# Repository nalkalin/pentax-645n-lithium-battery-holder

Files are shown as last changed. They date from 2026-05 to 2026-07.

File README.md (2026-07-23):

# Pentax 645N / 645N II Lithium Battery Holder

3D-printable battery holder for converting a Pentax 645N/645N II battery holder to rechargeable lithium power. The current design uses two 3.7 V lithium cells in series (2S: 7.4 V nominal, 8.4 V fully charged) with a 2S USB-C charge/boost module.

中文版: [点此跳转](README.zh-CN.md)

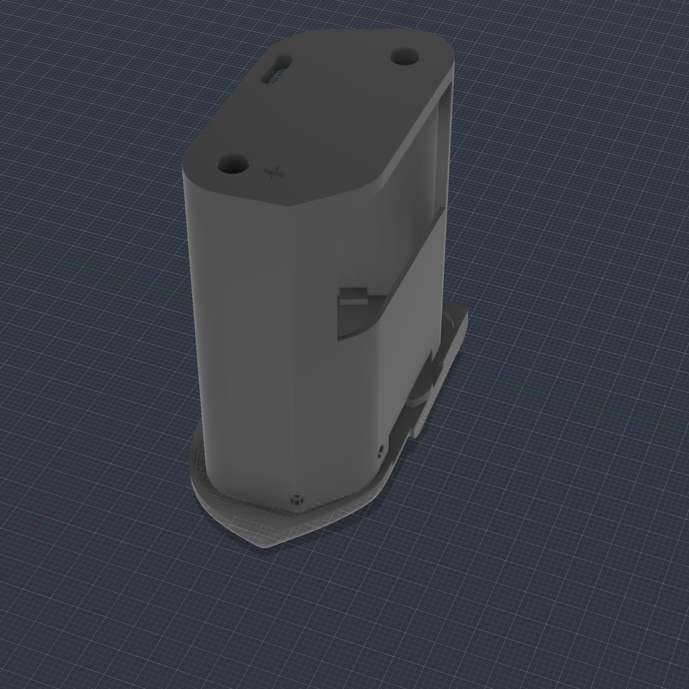
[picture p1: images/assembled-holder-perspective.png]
Assembled holder render


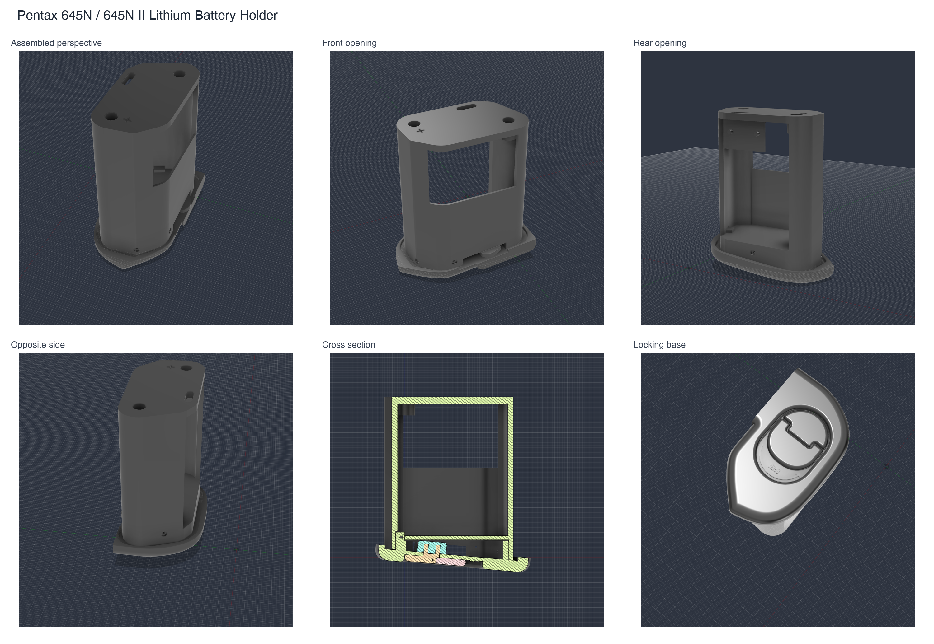
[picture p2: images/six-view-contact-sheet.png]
Six-view contact sheet


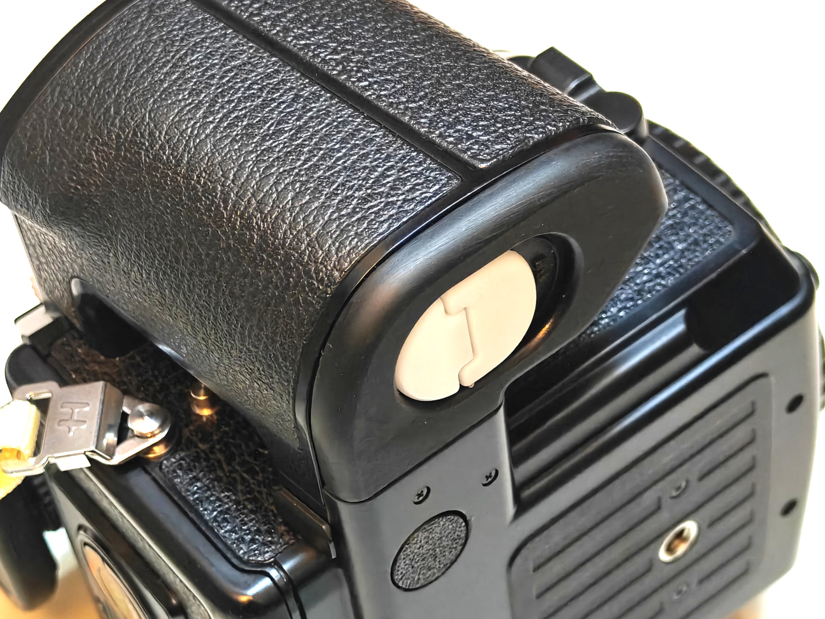
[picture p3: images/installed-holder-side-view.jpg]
Installed holder, side view


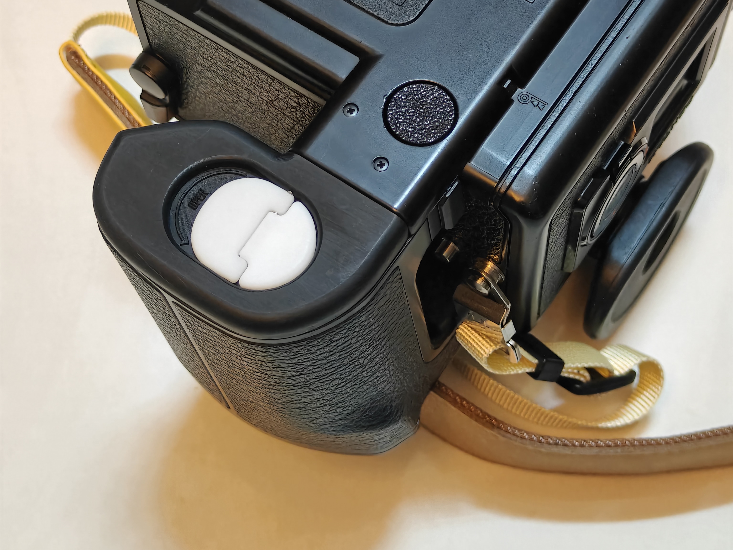
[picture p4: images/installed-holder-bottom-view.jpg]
Installed holder, bottom view


> Safety note: this is a DIY camera power modification. Use two cells of the same model, capacity, age, and state of charge. Verify the module output voltage, polarity, and absence of shorts with a multimeter before inserting the holder into a camera. Insulate all joints and contacts, and never use damaged, swollen, or overheating cells.

## Design Philosophy

The original Pentax 645N/645N II battery holder uses six AA alkaline batteries. That works, but it is not ideal for frequent use: disposable alkaline cells create avoidable waste, need to be replaced often, and make it easy to end up carrying extra batteries just to keep the camera running.

This project replaces that consumable setup with a rechargeable lithium pack. The goal is to keep these medium-format cameras practical for daily use while reducing reliance on single-use AA cells. Two series-connected lithium cells with a 2S charge/boost module offer several advantages:

- Rechargeable power instead of repeatedly buying and discarding alkaline batteries.
- USB-C charging, including from a wall charger, power bank, or field charging setup.
- A 7.4 V nominal 2S pack is sufficient regarding the voltage required by the camera.

## Compatible Models

- Pentax 645N
- Pentax 645N II

## Repository Contents

| Path | Description |
| --- | --- |
| `models/` | STL files for printing the holder and small contact/retainer parts. |
| `images/` | Reference renders and material photos. |
| `docs/bill-of-materials.md` | Parts list for the printed holder, electronics, fasteners, and wiring. |
| `docs/printing-and-assembly.md` | Suggested print settings and assembly checklist. |

## STL Files

All STL dimensions are in millimeters. Import at 100% scale.

| File | Approx. dimensions |
| --- | ---: |
| `models/pentax-645n-lithium-holder-body.stl` | 52.03 x 29.13 x 65.37 mm |
| `models/pentax-645n-lithium-holder-locking-base.stl` | 62.08 x 36.06 x 15.94 mm |
| `models/pentax-645n-lithium-holder-top-contact-retainer.stl` | 14.43 x 20.59 x 7.89 mm |
| `models/pentax-645n-lithium-holder-lower-contact-spacer.stl` | 12.09 x 24.78 x 5.48 mm |
| `models/pentax-645n-lithium-holder-bottom-contact-retainer.stl` | 15.02 x 21.20 x 3.69 mm |

## Print Notes

- Units: millimeters.
- Recommended process: SLA resin printing for better dimensional accuracy and small contact/screw features.
- Resin layer height: 0.03-0.05 mm.
- Supports: enable where your slicer shows unsupported overhangs, especially inside the main body and locking base. For resin printing, orient the parts to avoid suction cups and to protect contact surfaces.

Always test fit the printed parts before installing electronics.

## Materials

See [docs/bill-of-materials.md](docs/bill-of-materials.md) for the full list.

Core parts:

- Two matched 3.7 V lithium cells connected in series as a 2S pack.
- USB-C charge/boost module designed for a 2S pack; follow the markings and documentation supplied with the exact module.
- M2.5 x 6 mm brass thumb screw.
- M2.5 brass hex nut.
- M1.2 x 3 mm brass screw.
- Copper/brass/nickel strip for battery contacts, wire, heat-shrink, and insulation tape.

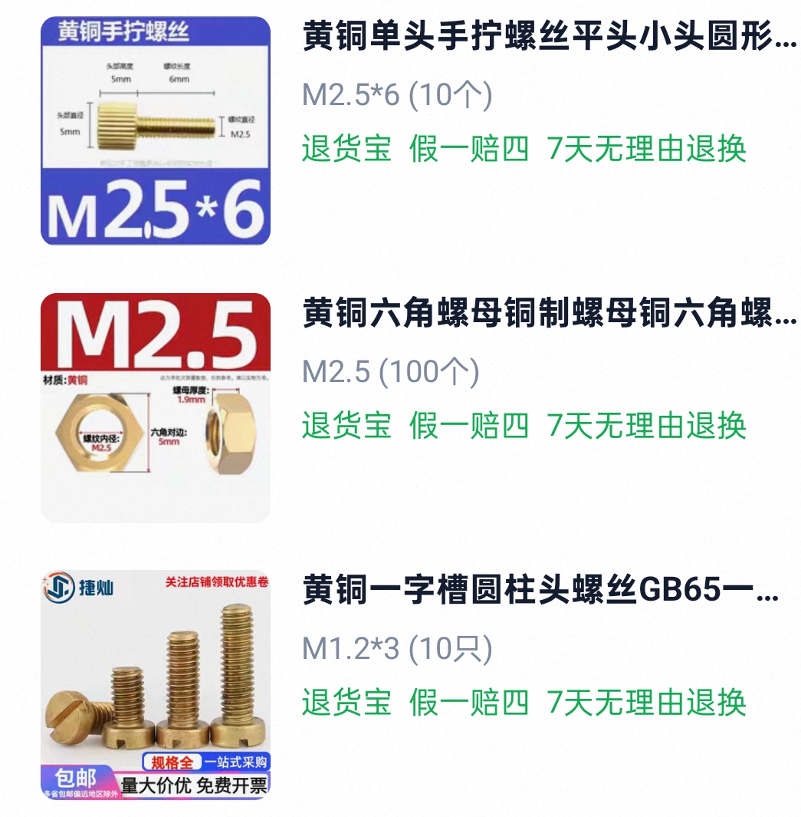
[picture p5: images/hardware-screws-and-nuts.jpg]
Materials reference


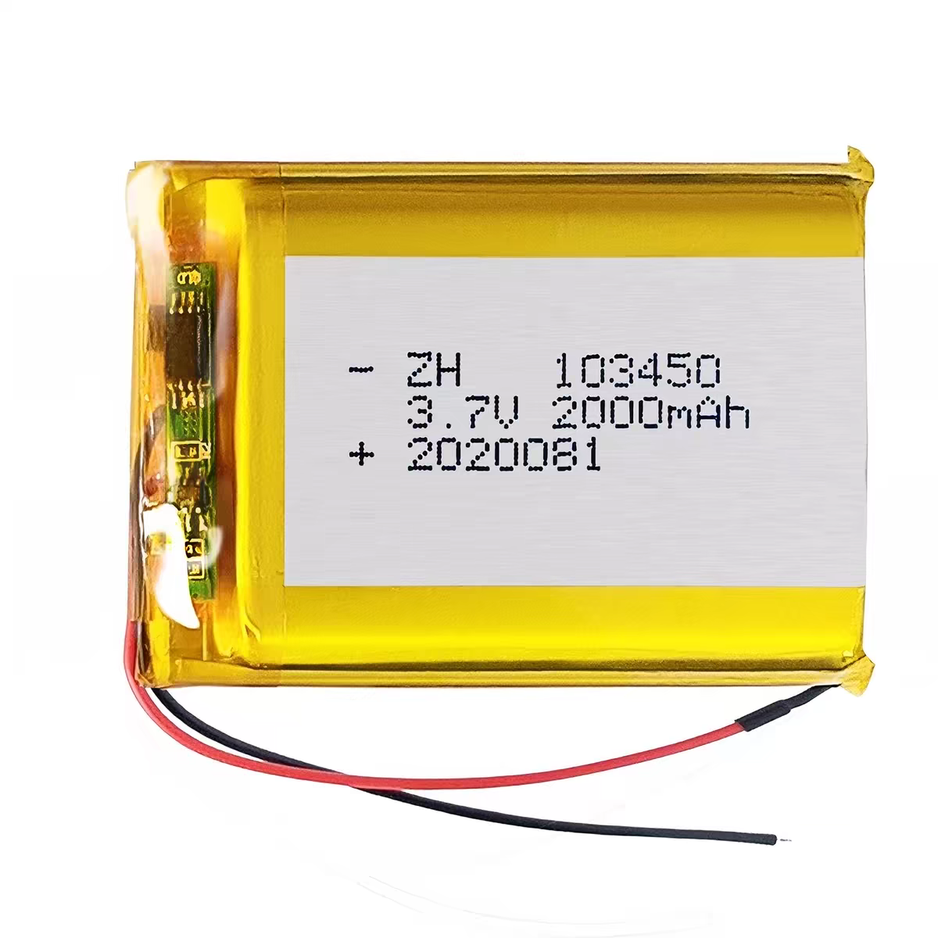
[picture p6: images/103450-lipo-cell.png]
Lithium cell size reference; two matched cells are required


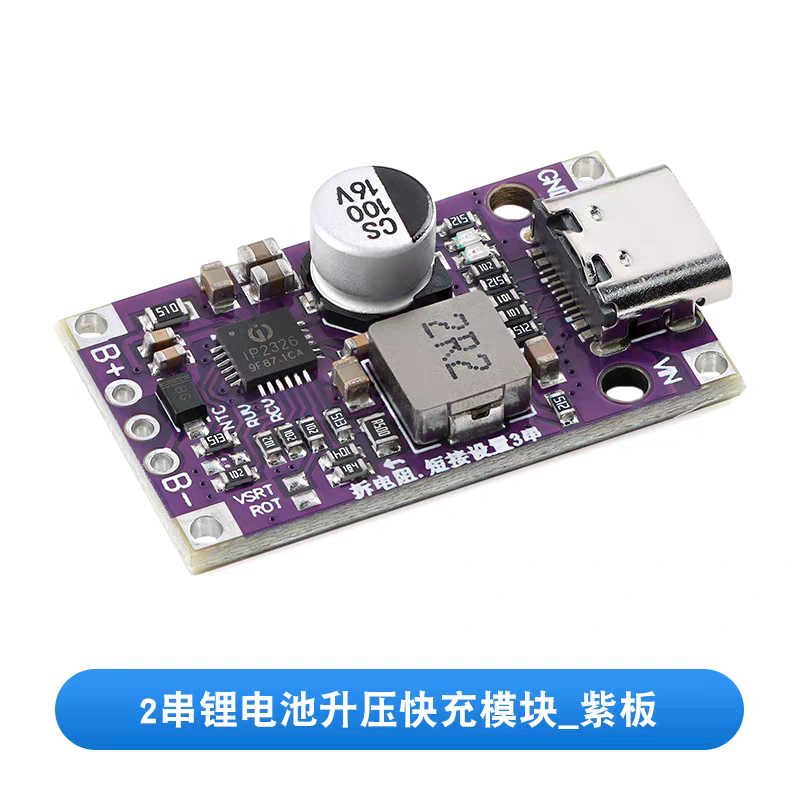
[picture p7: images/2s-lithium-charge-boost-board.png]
2S lithium charge/boost module


## Assembly Overview

1. Print all STL files at 100% scale.
2. Deburr the shell, contact slots, and screw holes.
3. Install the M2.5 nut/screw hardware and small printed retainers.
4. Fit two matched 3.7 V lithium cells and the 2S charge/boost board without pinching or bending either cell.
5. Connect the cells in series and wire the pack, protection/charging connections, and regulated output exactly as specified for the module being used.
6. Confirm pack voltage, regulated output voltage, polarity, and absence of shorts at the final camera-facing contacts with a multimeter.
7. Insulate exposed joints, close the holder, and do a camera fit check.

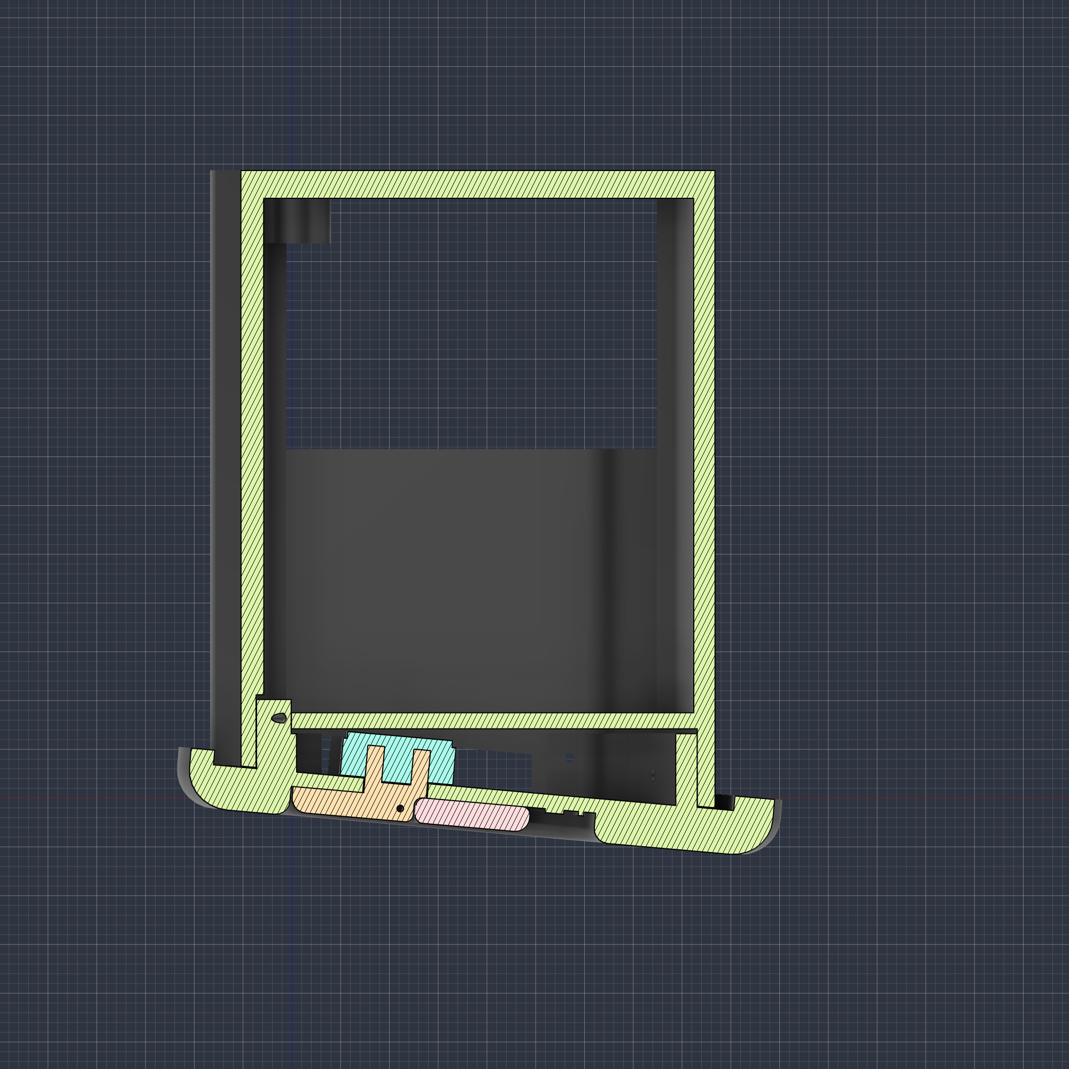
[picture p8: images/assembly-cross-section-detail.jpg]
Assembly cross section


## License

This project is released under the Creative Commons Attribution 4.0 International License. See [LICENSE](LICENSE).

Pentax is a trademark of Ricoh Imaging Company, Ltd. This project is an independent community design and is not affiliated with or endorsed by Ricoh/Pentax.

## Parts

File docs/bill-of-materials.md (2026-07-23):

# Bill of Materials

This list is based on the reference material images included in this repository. Equivalent parts may work if they match the electrical requirements and fit inside the printed holder.

## Printed Parts

| Quantity | File | Notes |
| ---: | --- | --- |
| 1 | `models/pentax-645n-lithium-holder-body.stl` | Main holder body. |
| 1 | `models/pentax-645n-lithium-holder-locking-base.stl` | Bottom locking/base part. |
| 1 | `models/pentax-645n-lithium-holder-top-contact-retainer.stl` | Small upper contact/retainer part. |
| 1 | `models/pentax-645n-lithium-holder-lower-contact-spacer.stl` | Small lower spacer/contact support. |
| 1 | `models/pentax-645n-lithium-holder-bottom-contact-retainer.stl` | Small lower contact/retainer part. |

## Electronics

| Quantity | Part | Notes |
| ---: | --- | --- |
| 2 | Matched 3.7 V lithium cells | Use the same model, capacity, age, and state of charge. Connect in series as a 2S pack (7.4 V nominal, 8.4 V fully charged). The 103450 image is a size reference only; verify that two selected cells fit safely. |
| 1 | 2S lithium charge/boost board, USB-C input | Must support charging/protection for the selected 2S pack. Follow the exact board's documentation and confirm the regulated output voltage before connecting the camera. |
| As needed | Flexible silicone wire | Use appropriate gauge for the current draw. |
| As needed | Heat-shrink, Kapton tape, or other insulation | Cover every exposed solder joint and metal edge near the LiPo cell. |

Lithium cell size reference

2S lithium charge/boost board

## Hardware

| Quantity | Part | Notes |
| ---: | --- | --- |
| 1 or more | M2.5 x 6 mm brass thumb screw | Used for the locking/contact hardware shown in the reference image. |
| 1 or more | M2.5 brass hex nut | Match the M2.5 screw. |
| 1 or more | M1.2 x 3 mm brass slotted screw | Small retaining screw. |
| As needed | Copper, brass, or nickel strip | For making the camera-facing electrical contacts. |

Hardware reference

## Electrical Checklist

- Confirm that the two cells are matched and connected as a 2S pack.
- Confirm that the protection/charging arrangement is intended for 2S operation.
- Confirm the boost board output voltage matches the camera's expected battery input.
- Confirm the final contact polarity before installing the holder.
- Check for shorts between positive and negative contacts.
- Do not let metal contacts rub into either lithium cell.
- Do not charge unattended.

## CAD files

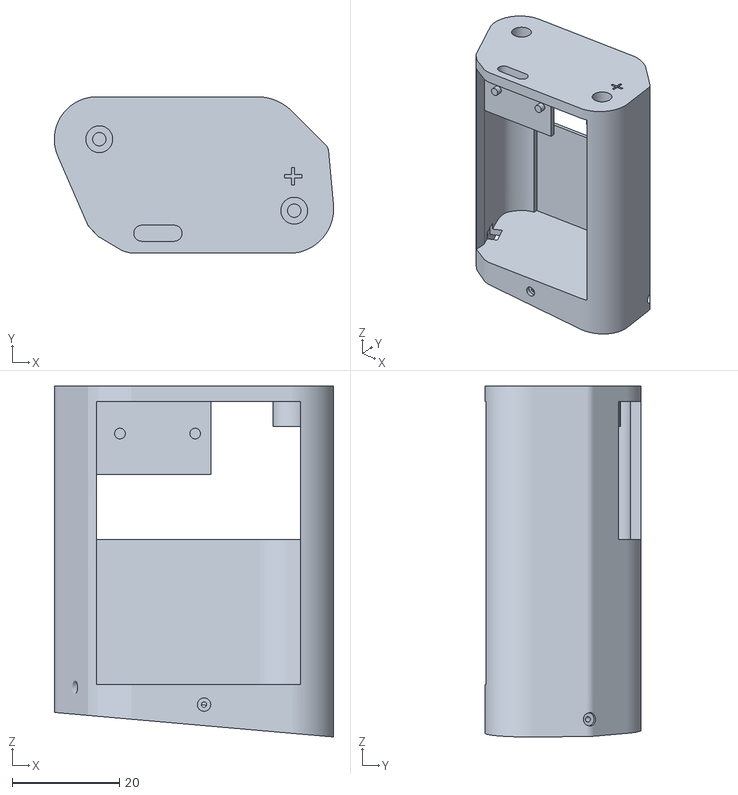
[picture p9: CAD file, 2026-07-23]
models/pentax-645n-lithium-holder-body.stl
52.0 x 29.1 x 65.4

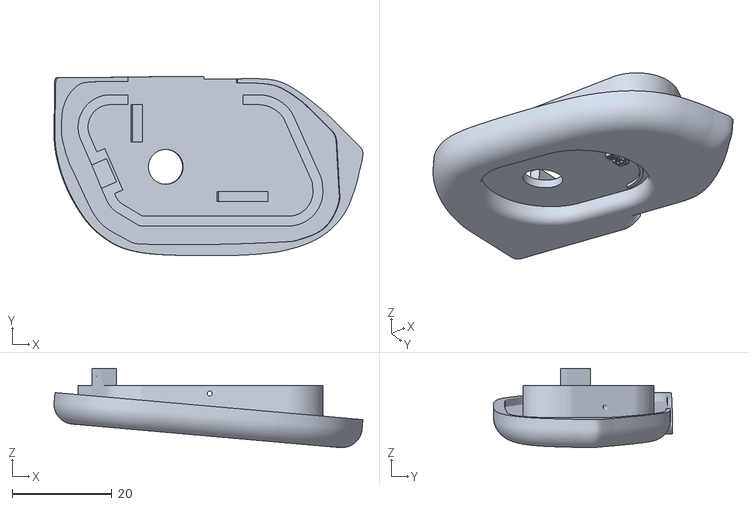
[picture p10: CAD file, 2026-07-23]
models/pentax-645n-lithium-holder-locking-base.stl
62.1 x 36.1 x 15.9

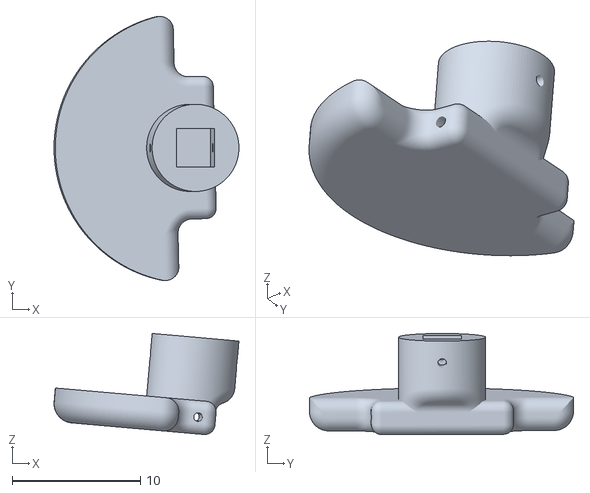
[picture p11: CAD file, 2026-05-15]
models/pentax-645n-lithium-holder-top-contact-retainer.stl
14.4 x 20.6 x 7.89

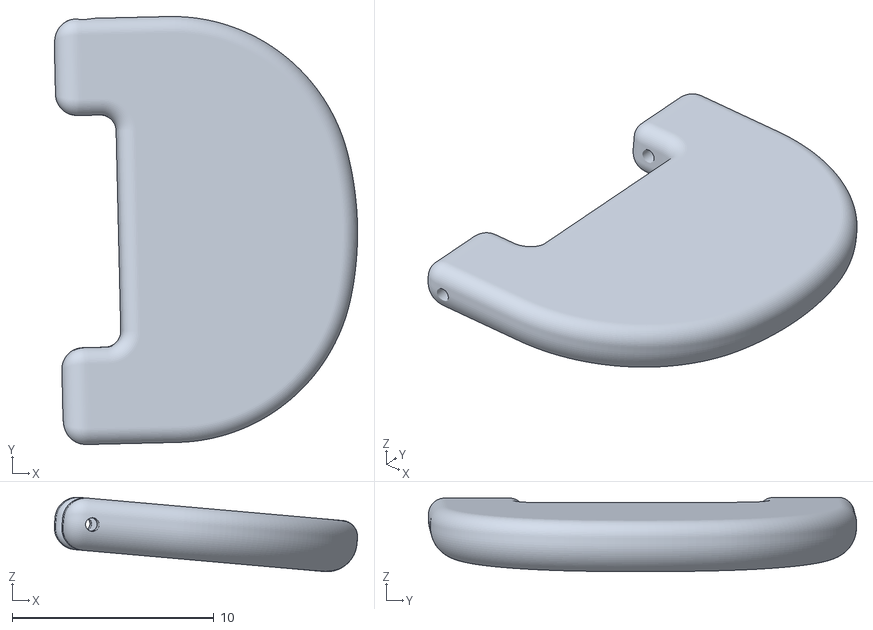
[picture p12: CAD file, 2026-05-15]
models/pentax-645n-lithium-holder-bottom-contact-retainer.stl
15.0 x 21.2 x 3.69

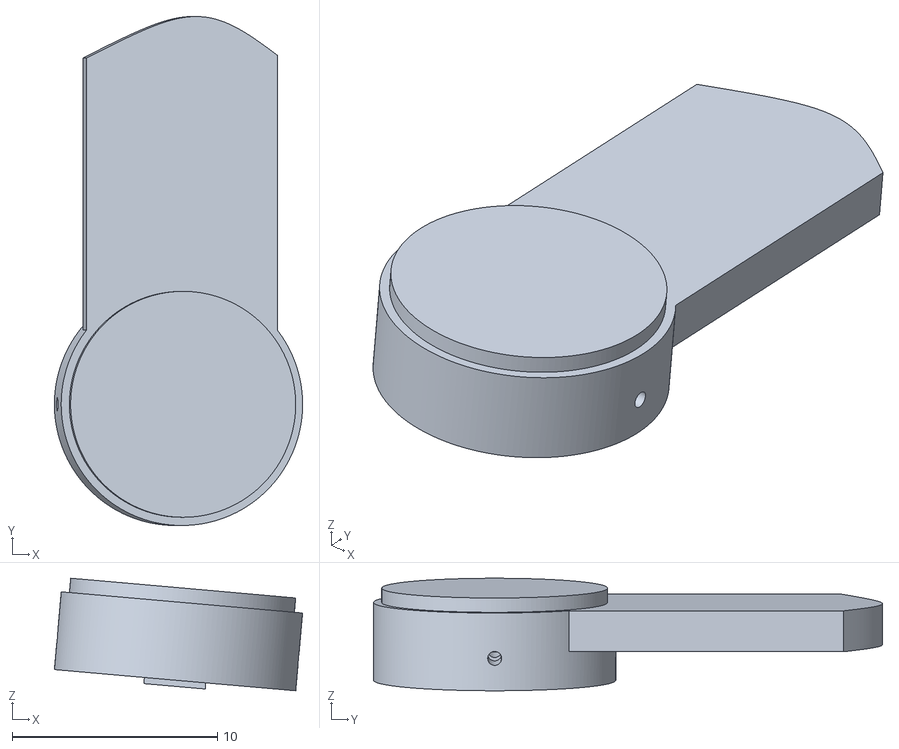
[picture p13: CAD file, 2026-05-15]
models/pentax-645n-lithium-holder-lower-contact-spacer.stl
12.1 x 24.8 x 5.48

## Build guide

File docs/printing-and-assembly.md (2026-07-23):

# Printing and Assembly Notes

## Printing

- Import STL files in millimeters at 100% scale.
- SLA/MSLA/DLP resin printing is recommended because the holder has small screw, contact, and locking features.
- Use tough resin, ABS-like resin, or another engineering resin with good impact resistance.
- Start with 0.03-0.05 mm resin layer height.
- Orient parts to protect the camera-facing surfaces, avoid suction cups, and keep supports away from critical contact slots where possible.

After printing, test the parts together before soldering any electronics. Lightly deburr the edges that contact the camera battery bay.

## Assembly

1. Dry-fit the main body and locking base.
2. Test the M2.5 and M1.2 hardware in the printed parts.
3. Shape the copper/brass/nickel strip contacts and confirm they sit flat in the printed retainers.
4. Place two matched 3.7 V lithium cells in the holder without pinching, bending, or rubbing either cell.
5. Connect the cells in series as a 2S pack and mount the 2S charge/boost board where the USB-C port and wiring remain accessible.
6. Wire the pack, protection/charging connections, and output leads according to the documentation and markings for the exact module being used.
7. Connect the regulated output to the camera-facing contacts.
8. Use a multimeter to check pack voltage, regulated output voltage, polarity, continuity, and absence of shorts.
9. Insulate exposed solder joints and sharp metal edges.
10. Install the holder into the camera only after the electrical checks pass.

## Reference Views

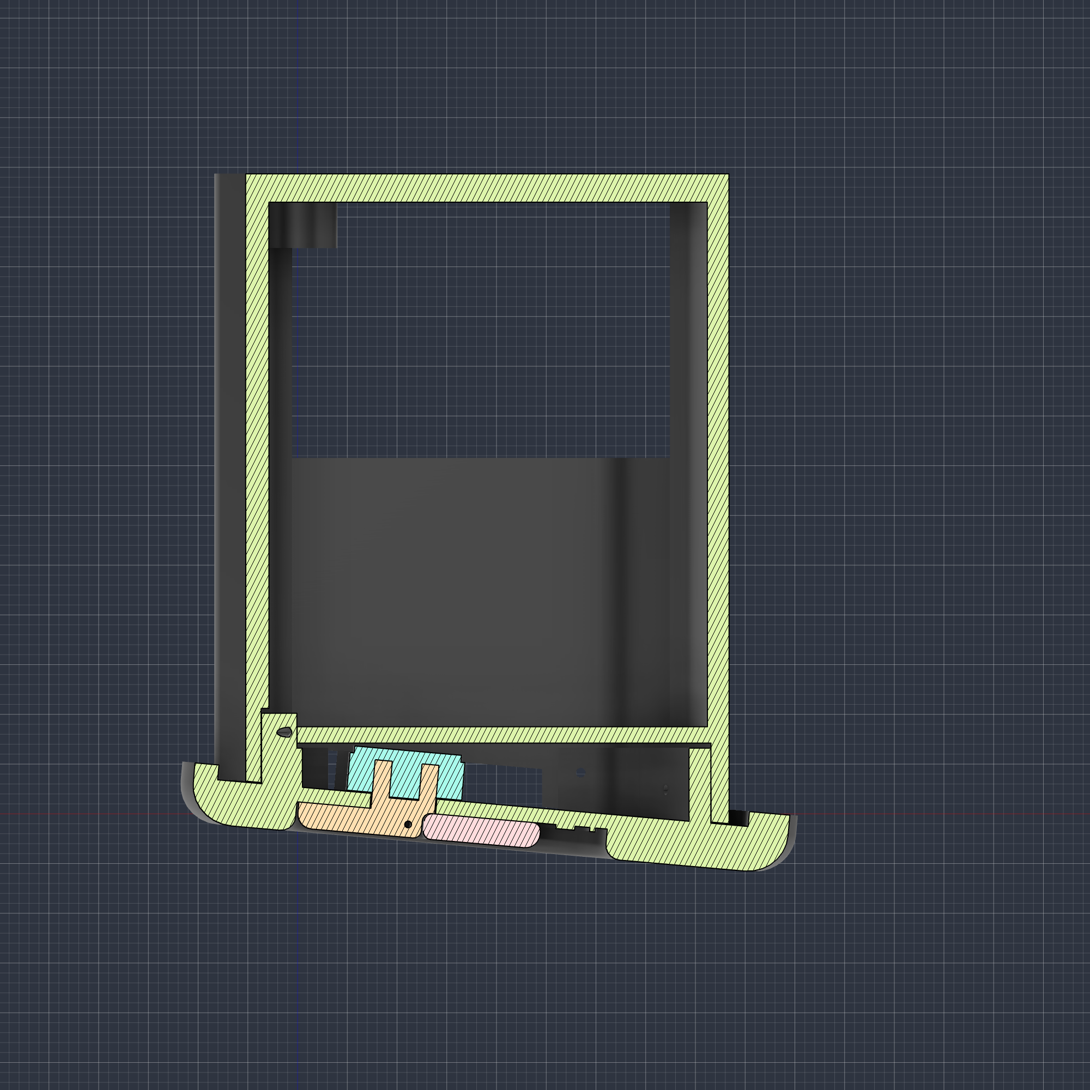
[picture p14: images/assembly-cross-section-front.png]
Front cross section


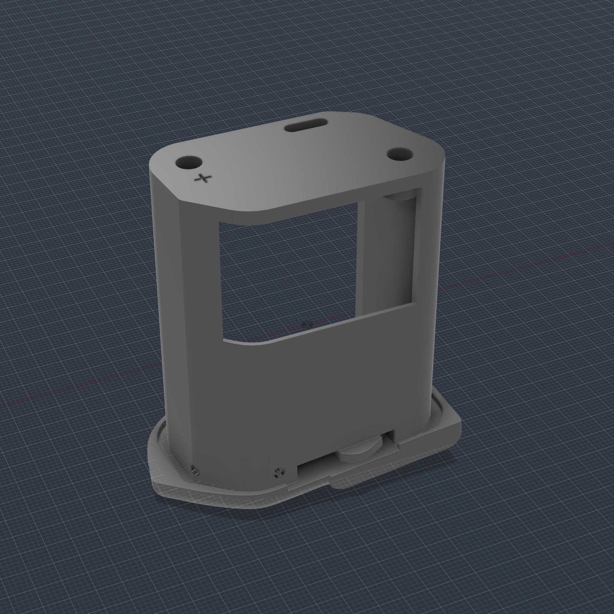
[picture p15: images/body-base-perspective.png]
Body/base perspective


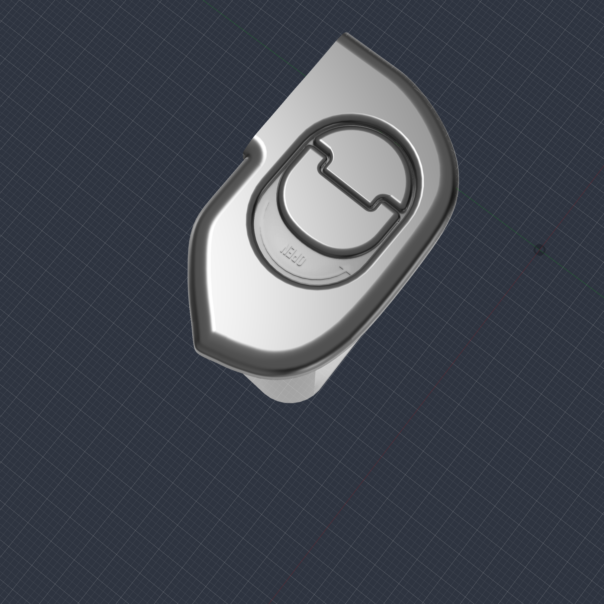
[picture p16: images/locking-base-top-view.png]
Locking base top view


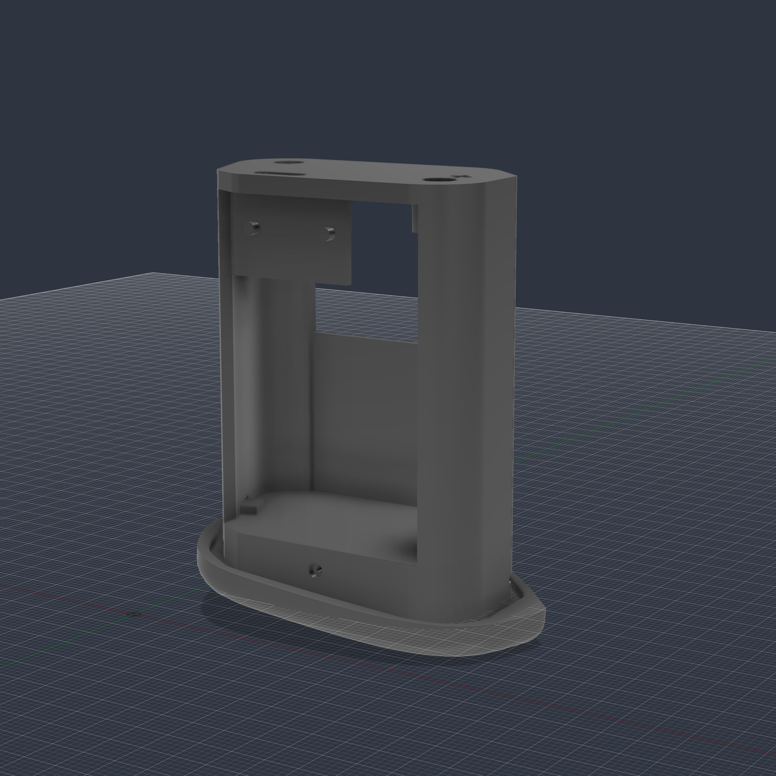
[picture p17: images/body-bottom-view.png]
Body bottom view


## Safety

Lithium cells can be damaged by puncture, crushing, over-discharge, over-charge, imbalance, or short circuits. Do not mix cell models, capacities, ages, or states of charge in the 2S pack. If either cell becomes hot, swollen, punctured, or smells unusual, stop using the pack immediately and dispose of it according to local battery rules.

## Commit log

2026-05-15 Initial open-source release
    [pentax-645n-lithium-holder-body.stl, pentax-645n-lithium-holder-bottom-contact-retainer.stl, pentax-645n-lithium-holder-locking-base.stl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]
2026-05-15 Add Chinese README and resin print guidance
2026-05-15 Add battery conversion philosophy
2026-07-23 Update holder for 2S lithium battery configuration
    [pentax-645n-lithium-holder-body.stl, pentax-645n-lithium-holder-locking-base.stl]
